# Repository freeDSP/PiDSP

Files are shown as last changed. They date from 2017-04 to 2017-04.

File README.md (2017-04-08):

# PiDSP
Home of PiDSP - a freeDSP for Raspberry Pi

PiDSP is a DSP board built around ADAU1452, with use of Raspberry Pi compatible SBC in mind.
For more details please see:

[PiDSP Manual](https://docs.google.com/document/d/19vuj6VbJ9ktcaG_P7PJXTnH1ImkcPwiqC4xYBWqMJs8)

[Developement thread](http://www.diyaudio.com/forums/digital-line-level/268660-freedsp-v2-0-adau1452-developement-thread-20.html)

**Specifications:**

* Power supply 12V
* Logic level 3.3V  NOT 5V TOLERANT!!
* PCB:10cmx10cm 4L - nope, you can not etch it on your sink. But it fits into 10x10cm dimension limit of cheap fab houses :)
* Inputs: 1xSPDIF, 4xI2S - TDM capable
* Outputs: 1xSPDIF, 4xI2S - TDM capable
* ADAU1452 controls: 4 analog controls, 4 digital controls
* Other: 
  * Connector for Raspberry Pi compatible SBC connector, 
  * USBi connector
  * Power management

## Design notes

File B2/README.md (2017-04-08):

# Version B2

This version is functional with some minor modification. This is not the final version. Developement is underway to fix the bugs.
Due to BOM generation, schematics contains some parts that are not present on the pcb. Schematics and PCB are not synchronized. PCB is as it was at time of gerber generation. 

"Bugs highlight":
* DSP_Disable signal is not working - it will turn-off whole board
* Missing fixing pads for Tosling - you need to glue it
* jumper wire needed for one timing capacitors 

[Buglist](https://docs.google.com/spreadsheets/d/1_dzgIj09PDWNxM0hXiN3Wn4PsSBpoaOSRhSJXX5WdX8/edit#gid=567249624)

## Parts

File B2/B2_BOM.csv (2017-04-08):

Designator | Quantity | Comment | Description | Supplier 1 | Supplier 2 | Supplier Part Number 1 | Supplier Part Number 2 | Footprint
CK1, CK3, CK4, CK5, CK6, CK7, CK8, CK10, CK11, CK12, CK14, CK15, CK16, CK17, CK18, CK19, CK20, CK21, CK22, CK23, CK34, CK35, CK36, CK37, CK38, CK39, CK42, CK43, CK48, CK51, CK52, CK53, CK54, CK65, CK68, CK70, CK71, CK72, CK73, CK74, CK75, CK76, CK77, CK78, CK79, CK80, CK83 | 47 | 100n | MLCC | Mouser |  | 81-GRM39X104K50D |  | CAPC1608X09N(SMC0603)
CK46, CK63, CK64, CK91, CK92, CK93, CK98, CK99, CK100, CK101, CK102, CK103, CK104, CK105, CK106, CK107, CK123, CK124, CK125 | 19 | 10n | MLCC | Mouser |  | 81-GRM39X103K50D |  | CAPC1608X09N(SMC0603)
CK2, CK25, CK26, CK27, CK28, CK29, CK30, CK41, CK44, CK45, CK47, CK56, CK59, CK61, CK62, CK81, CK82, CK88 | 18 | 10u | MLCC | Mouser |  | 81-GRM31CR61H106MA2L |  | CAPC3216X12N(SMC1206)
R1, R2, R3, R6, R8, R16, R18, R19, R26, R27, R28, R29, R30, R31, R40, R61, R65 | 17 | 22R | Chip Resistor | Mouser |  | 603-RC0603FR-0722RL |  | RESC1608X06N(SMR0603)
R5, R9, R11, R12, R14, R22, R23, R24, R25, R35, R63, R67 | 12 | 4k3 | Chip Resistor | Mouser |  | 603-RC0603FR-074K3L |  | RESC1608X06N(SMR0603)
R10, R21, R42, R43, R66, R76, R81, R88 | 8 | 10k | Chip Resistor | Mouser |  | 603-RC0603FR-0710KL |  | RESC1608X06N(SMR0603)
R44, R45, R46, R47, R48, R49, R50, R51 | 8 | 100R | Chip Resistor | Mouser |  | 603-RC0603FR-07100RL |  | RESC1608X06N(SMR0603)
R17, R20, R57, R71, R83, R90 | 6 | 220k | Chip Resistor | Mouser |  | 603-RC0603FR-07220KL |  | RESC1608X06N(SMR0603)
CE1, CE7, CE14 | 3 | 330u | Polymer Aluminium Solid Capacitor 330uF, 6.3V | Mouser |  | 710-875105144010 |  | CAPAE6.8X6.8(D_SIZE)
CK31, CK32, CK66 | 3 | 22p | MLCC | Mouser |  | 81-GCM1885C1H220J16D |  | CAPC1608X09N(SMC0603)
DIO 0, DIO 1, DIO 2 | 3 | EJ-MLW16G | IDC Male Header for PCB 2x8 Pin, Straight | Mouser |  | 710-61201621621 |  | MLW16G
L5, L8, L9 | 3 | 1500R/100MHz | Multilayer SMD Ferrite 1500R/100MHz | Mouser |  | 810-MMZ2012Y152B |  | INDC2012X08N(SML0805)
R38, R68, R84 | 3 | 2k7 | Chip Resistor | Mouser |  | 603-RC0603FR-072K7L |  | RESC1608X06N(SMR0603)
T2, T3, T4 | 3 | BSS138 | N-MOSFET, Logic Level, 50V/0,22A/3.5Ohm | Mouser |  | 512-BSS138 |  | SOT95P230X110-3N(SOT23)
CE2, CE6 | 2 | 100u | Polymer Aluminium Solid Capacitor 100uF, 16V | Mouser |  | 710-875105344010 |  | CAPAE6.8X6.8(D_SIZE)
J7, J9 | 2 | UFL | Subminiature connector | Mouser |  | 571-1909763-1 |  | U.FL-R-SMT
L1, L2 | 2 | 6.8u/1.5A | Low Profile, High Current Inductor | Mouser |  | 70-IFSC1515AHER6R8M0 |  | INDM_3.8x3.8x1.8
X1, X2 | 2 | NZ2520SD | Low Phase Noise Oscillator |  |  |  |  | 2.5x2mm osclillator
CK13 | 1 | 150p | MLCC | Mouser |  |  |  | CAPC1608X09N(SMC0603)
CK9 | 1 | 5.6n | MLCC | Mouser |  |  |  | CAPC1608X09N(SMC0603)
DL3 | 1 | GREEN | Green LED, 0603 | Mouser |  | 710-150060GS75000 |  | 0603diode
DS1 | 1 | 5A/40V | High Current Density SMT Schottky Rectifier, 5A/40V, SMC | Mouser |  | 625-SSC54-E3 |  | DIOM6959X26M(SMC)
DS2 | 1 | B340A | High Current Density SMT Schottky Rectifier, 3A/40V, SMA | Mouser |  | 621-B340-F |  | DIOM5127X23N(SMA)
DZ1 | 1 | SMAJ24CA | Surface Mount TVS, Bidirectional, 12V DC Standoff, 1.5kW, SMC | Mouser |  | 652-SMAJ16CA |  | DIOM5127X23N(SMA)
J1 | 1 | NEB 21R | Power Jack Socket 1.95/6mm | Mouser | Farnell | 490-PJ-050AH | 1217037 | NEB 21 R
J11 | 1 | 2x5 | IDC Male Header for PCB 2x5 Pin, Straight | Mouser |  | 710-61201021621 |  | MLW10G_BK
J6 | 1 | MLW 2x10 | MLW 2x10 | Mouser |  | 710-61202021621 |  | MLW20G_BG
L3 | 1 | 3.3uH/6.5A | SRP6540 Series - Shielded Power Inductors | Mouser |  | 652-SRP6540-3R3M |  | INDM_7.2x6.5
L6 | 1 | 500Ohm/100MHz | CHOKE, COMMON, 4A, 500OHM, 100MHZ | Mouser |  | 81-DLW5BTM501SQ2L |  | DLW5BT
R33 | 1 | 0R1 | Chip Resistor | Farnell |  | 8867364 |  | RESC1608X06N(SMR0603)
R36 | 1 | 820R | Chip Resistor | Mouser |  | 603-RC0603FR-07820RL |  | RESC1608X06N(SMR0603)
R39 | 1 | 150k | Chip Resistor | Mouser |  | 603-RC0603FR-07150KL |  | RESC1608X06N(SMR0603)
R72 | 1 | 47k | Chip Resistor | Mouser |  | 603-RC0603FR-0747KL |  | RESC1608X06N(SMR0603)
R86 | 1 | 56k | Chip Resistor | Mouser |  | 603-RC0603FR-0756KL |  | RESC1608X06N(SMR0603)
T1 | 1 | FDC658AP | 30V P - Channel PowerTrench MOSFET | Mouser |  | 512-FDC658AP |  | TSOP95P280X110-6N(SuperSOT6)
U1 | 1 | ADAU1452 | ADAU1452 | Mouser |  | 584-ADAU1452WBCPZ |  | CP_72_6-handsoldering
U10 | 1 | LP5907 3.3V | Ultra Low-Noise, 250-mA Linear Regulator | Mouser | Digi-Key | 595-LP5907MFX-3.3NPB | 296-38557-1-ND | SOT95P280X90-5N(SOT23-5)
U11 | 1 | TPS54292 | 1.5-A/2.5-A Dual, Fully-Synchronous Buck Converter | Mouser |  | 595-TPS54292PWPR |  | TSOP65P640X120_HS-17M(TSSOP16-TP)
U14 | 1 | CAT24C512 | 512 Kb I2C CMOS Serial EEPROM | Mouser |  | 863-CAT24C512WI-GT3 |  | SOIC127P600X175-8N(SOIC_8)
U15 | 1 | SP4065 | 3.3V 20A Diode ESD Array | Mouser |  | 576-SP4065-08ATG |  | TSSOP50P490X110-10N(MSOP10)
U2 | 1 | Si53360 | 1:8 LOW JITTER CMOS CLOCK BUFFER WITH 2:1 INPUT MUX | Mouser |  | 634-SI53360-B-GT |  | TSOP65P640X120-16N (TSSOP16-4.4MM)
U4 | 1 | RPi B+/2/3 | Rapsberry Pi Header | Mouser |  | 517-929975-01-20 |  | RPi B+
U6 | 1 | OTJ-8 | Toslink Transmitter | TME |  | FC684208T |  | OTJ/ORJ 8
U7 | 1 | ORJ-8 | Toslink Reciever | TME |  | FC684208R |  | OTJ/ORJ 8
U8 | 1 | LTC2950-1 | Pushbutton On/Off Controller | Farnell |  | 2115908 |  | LT-TS8-8-TSOT-23_V
U9 | 1 | TPS54360 | 3.5 A, Step Down DC-DC Converter | Mouser |  | 595-TPS54360DDAR |  | SOIC127P600X175-8N(SOIC_8)-POWERPAD

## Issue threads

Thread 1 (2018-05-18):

Where to order PCB?

mbt28, 2018-05-18:
Hi,

How is the development status of beta revision? Can you please tell me low-cost pcb ordering place for the piDSP?

Thanks

Pitrsek, 2018-05-22:
Hi,
last time I've ordered from elecrow, but there are many possibilities. If you don't mind B2 version, i can put one or two into an envelope and send it your way :). B2 is missing possibility to turn of freedsp expansion boards(and some minor fixable bugs).I can add two milled boards that will add the turn off capability and fix startup timing.
About next version - i've finished incorporating all the changes and checked the design, I need to upload it for a review and order boards. My guess is that I'll have it tested by mid summer.

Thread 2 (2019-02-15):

Pinout of Toslink wrong?

DanieGieb, 2019-02-15:
Hello,

I am currently designing a board and use your implementation as a good  inspiration ;-)
Did you already tested the Toslink part?

In the Schematic the receiver U7 (ORJ-8) and the transmitter U6 (OTJ-8) have different pining as specified by the datasheet.

Datasheets:
Receiver: [http://www.cliffuk.co.uk/products/optical/FCR684208R.pdf](url)
Transmitter: [http://www.cliffuk.co.uk/products/optical/FCR684208T.pdf](url)

Maybe you have different footprint numbering and therefore it is correct?
Or is the part wrong?
By the way: Do you suggest to use this part? Availability?

Kind Regards
Daniel

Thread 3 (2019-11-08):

B3 still work in progress?

unre4l, 2019-11-08:
Great project so far! I am wondering if there is any active development going on?

Pitrsek, 2019-12-30:
Hello Jonathan, not really. I have a few boards that are up and running, I have made some final modifications, but I did nod had energy to push them and finish it up. ie. built the final design for verification. Life happened - I changed job and country, this Xmass we have moved again. I have some spare boards left, if you dont mind adding a few wires here and there.

Cheers,
Jan

myreauks, 2023-04-02:
Hi!

I am digging up this thread from a long time ago. I would be interested in carrying on this project. I have designed my own ADAU1701 board to be used with raspi but would like to transfer my design to use ADAU1452 to have easy support for S/PDIF. Do you have any documentation on the changes you were about to make for the B3 version of the board? Or on the off chance you would still have some B2 board lying around, would you be willing to sell one for testing purposes?

Best regards,
Miro

Pitrsek, 2023-04-04:
Hi,
if I remember correctly there was some minor bug wrt soft start. I can take a look at the board I've been using ever since, take a picture and write few notes about what and why was modified. I do still have some boards. How many you'd need? I'll be happy to send them your way.

Cheers,
Jan

myreauks, 2023-04-05:
Nice, that would be awesome! I'll contact you through your website.

Best,
Miro

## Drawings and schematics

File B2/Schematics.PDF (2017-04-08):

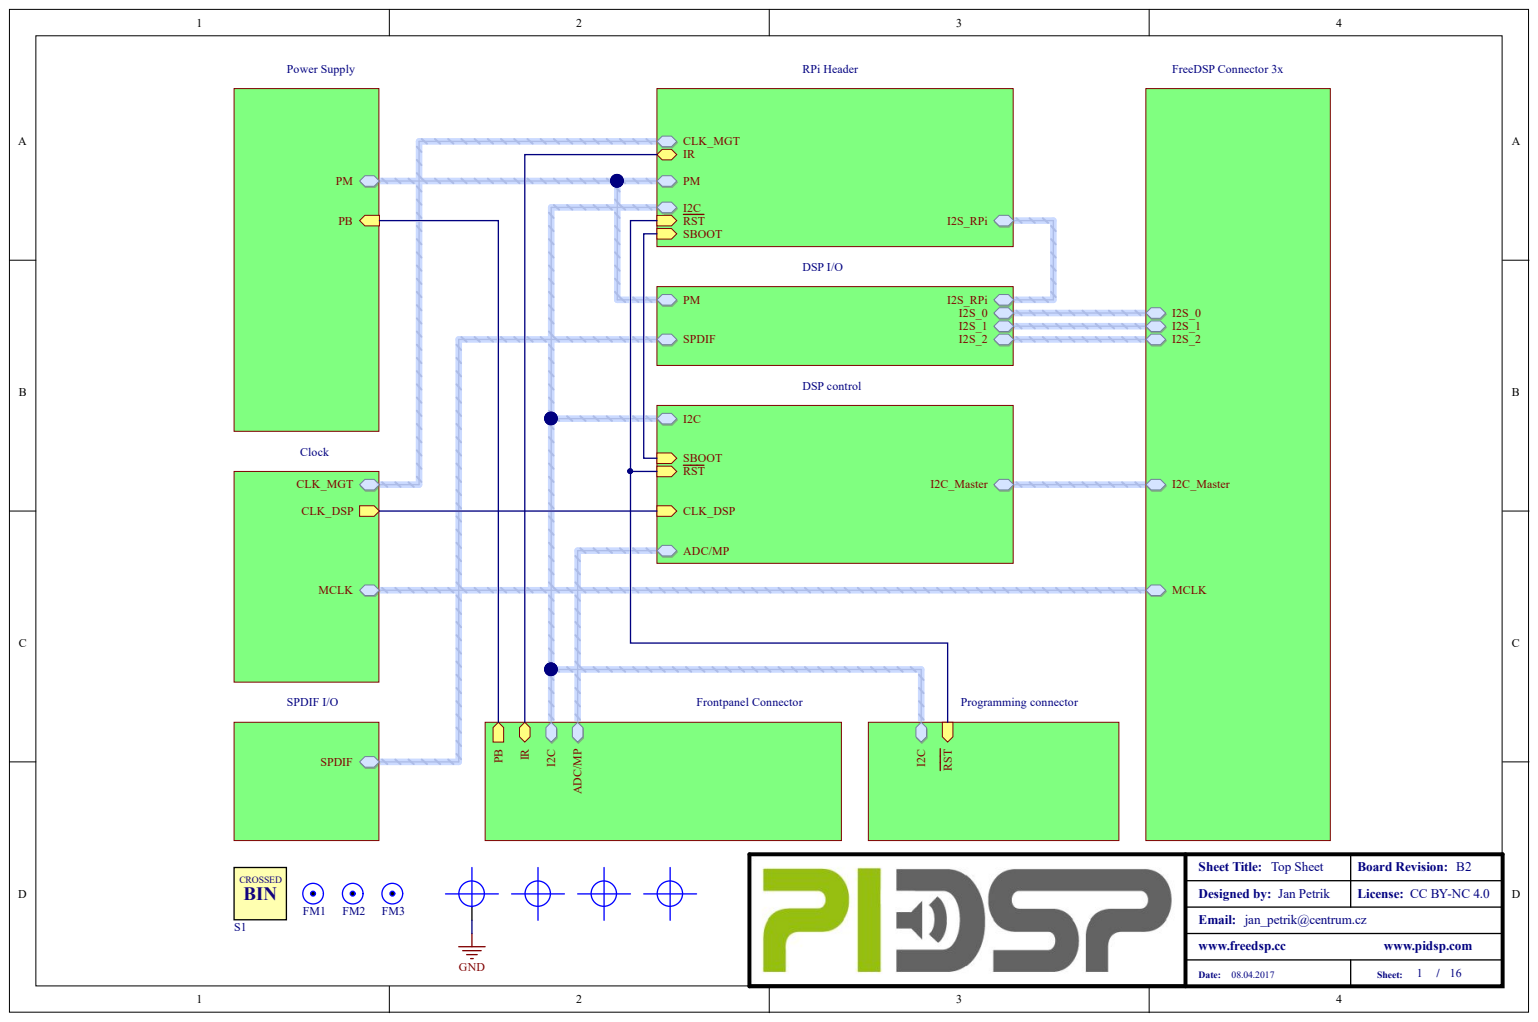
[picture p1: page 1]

Fro n t panel Co n nect o r

SPDIF

S h e et T itl e : Top She e t | Boar d R evi s ion : B2

D e s ign e d by: J an P e tri k | Li c e n s e : CC BY-NC 4. 0

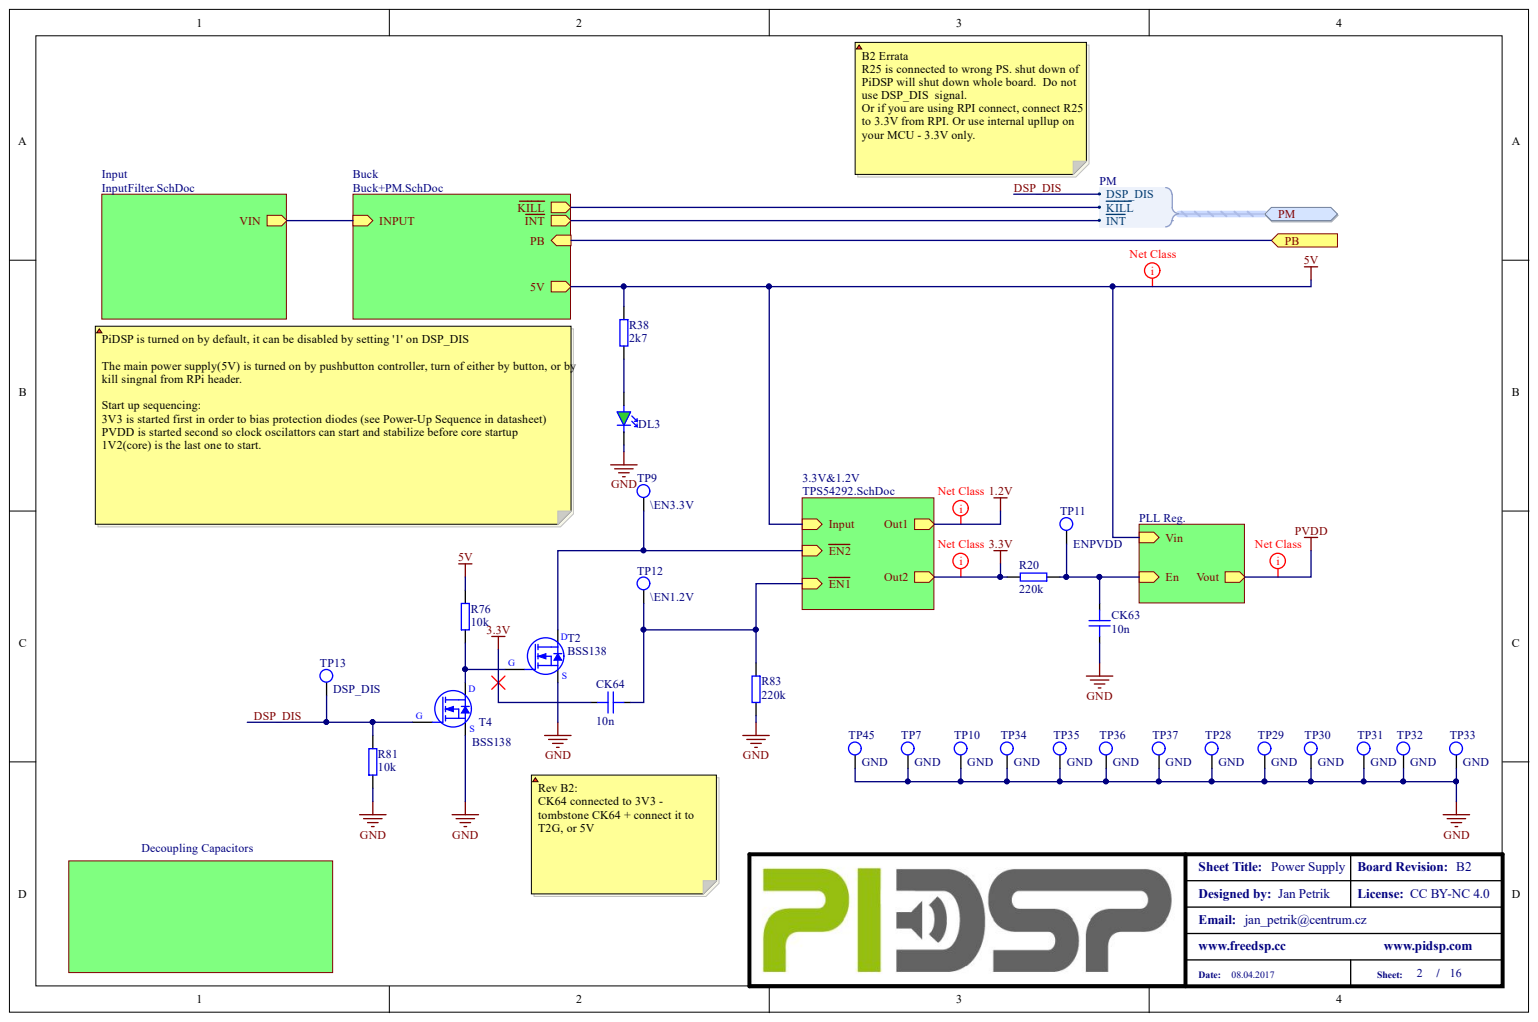
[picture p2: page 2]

B2 Errata
R25 is connected to wrong PS. shut down of
PiDSP will shut down whole board. Do not
use DSP_DIS signal.
Or if you are using RPI connect, connect R25
to 3.3V from RPI. Or use internal upllup on
your MCU - 3.3V only.

PiDSP is turned on by default, it can be disabled by setting '1' on DSP_DIS

The main power supply(5V) is turned on by pushbutton controller, turn of either by button, or by
kill singnal from RPi header.

Start up sequencing:
3V3 is started first in order to bias protection diodes (see Power-Up Sequence in datasheet)
PVDD is started second so clock oscilattors can start and stabilize before core startup
1V2(core) is the last one to start.

Rev B2:
CK64 connected to 3V3 -
tombstone CK64 + connect it to

Sheet Title: Power Supply | Board Revision: B2

Designed by: Jan Petrik | License: CC BY-NC 4.0

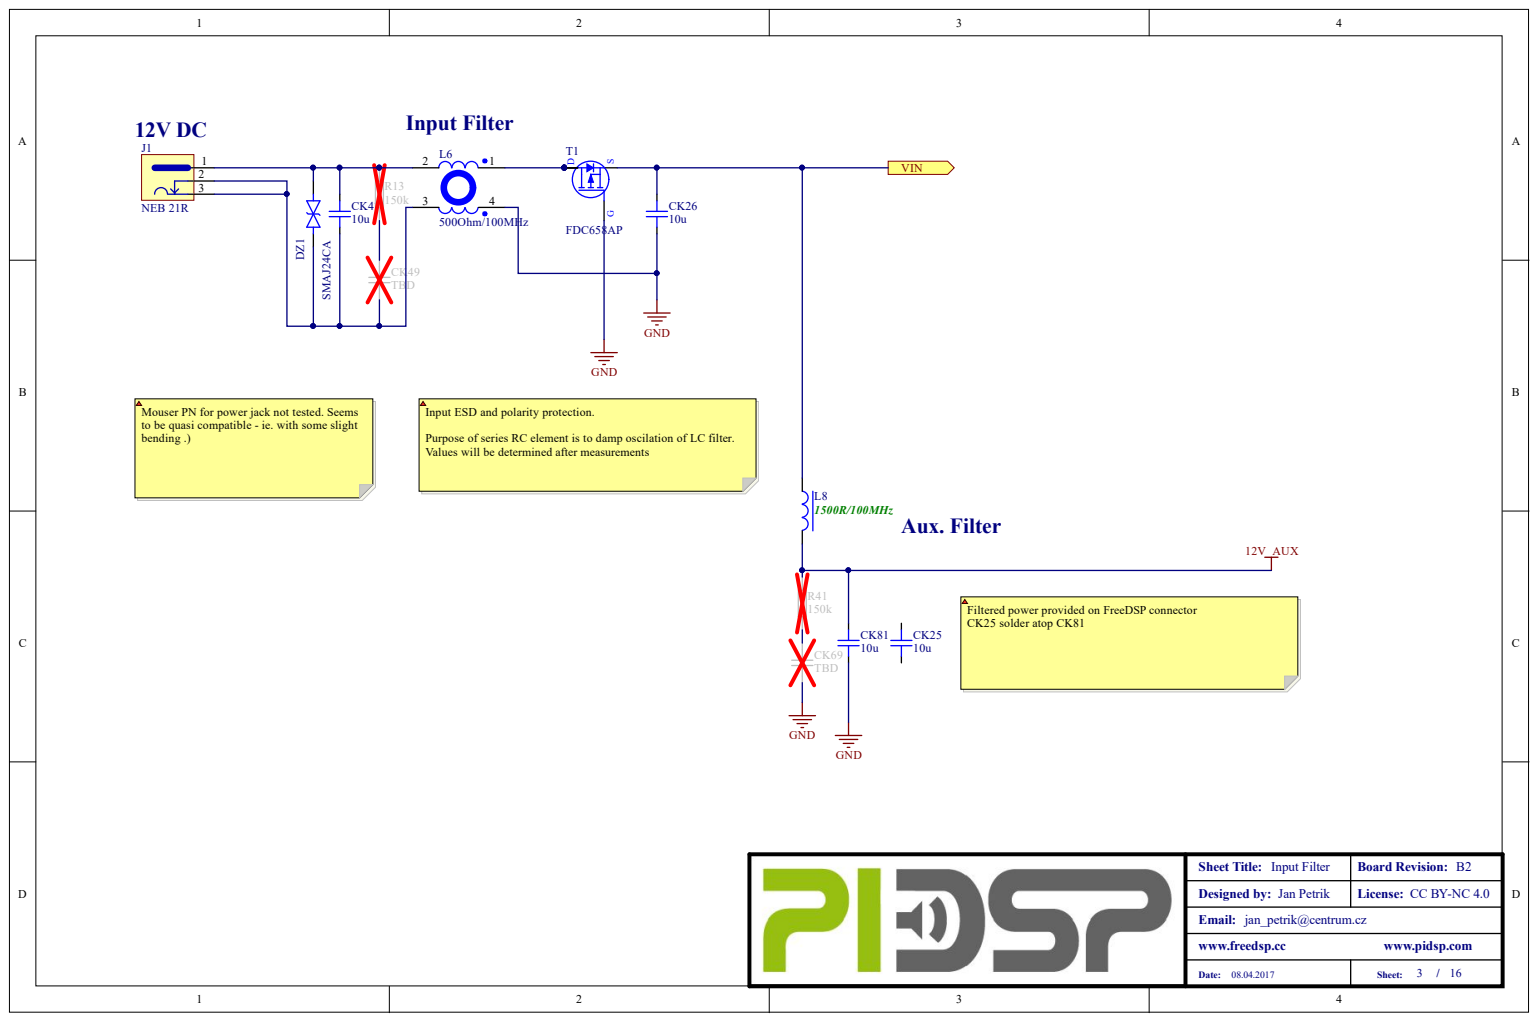
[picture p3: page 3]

Mouser PN for power jack not tested. Seems
to be quasi compatible - ie. with some slight
bending .)

Input ESD and polarity protection.

Purpose of series RC element is to damp oscilation of LC filter.
Values will be determined after measurements

Filtered power provided on FreeDSP connector
CK25 solder atop CK81

Sheet Title: Input Filter | Board Revision: B2

Designed by: Jan Petrik | License: CC BY-NC 4.0

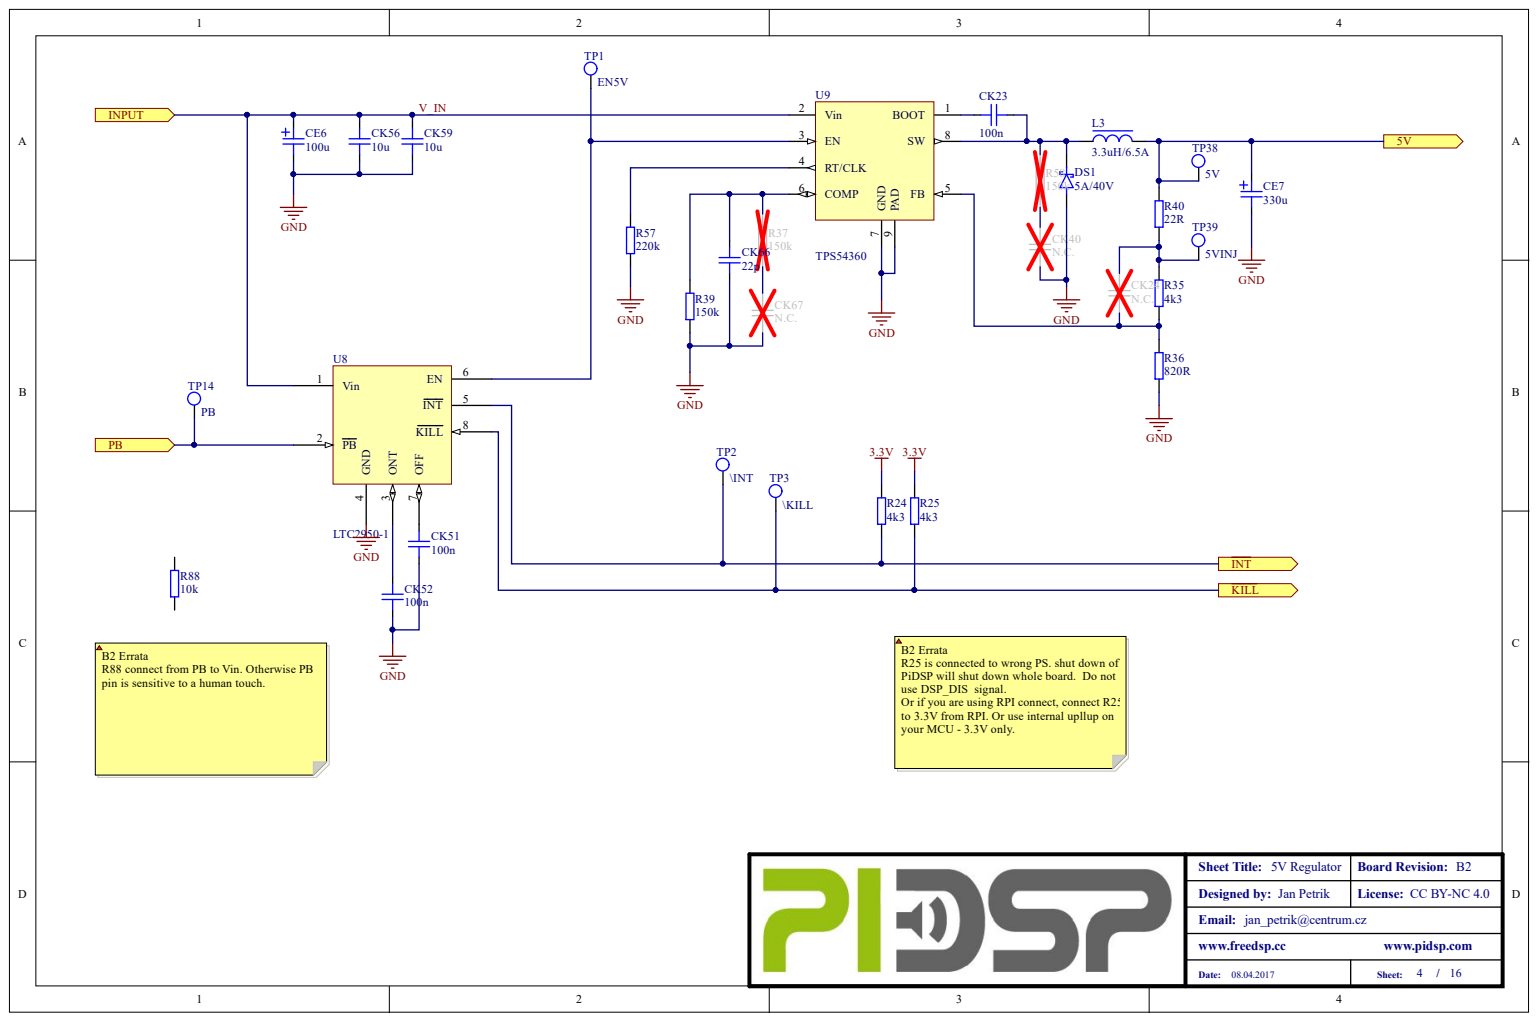
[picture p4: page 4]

S h e et T itl e : 5V Regul a tor | Boar d R evi s ion : B2

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

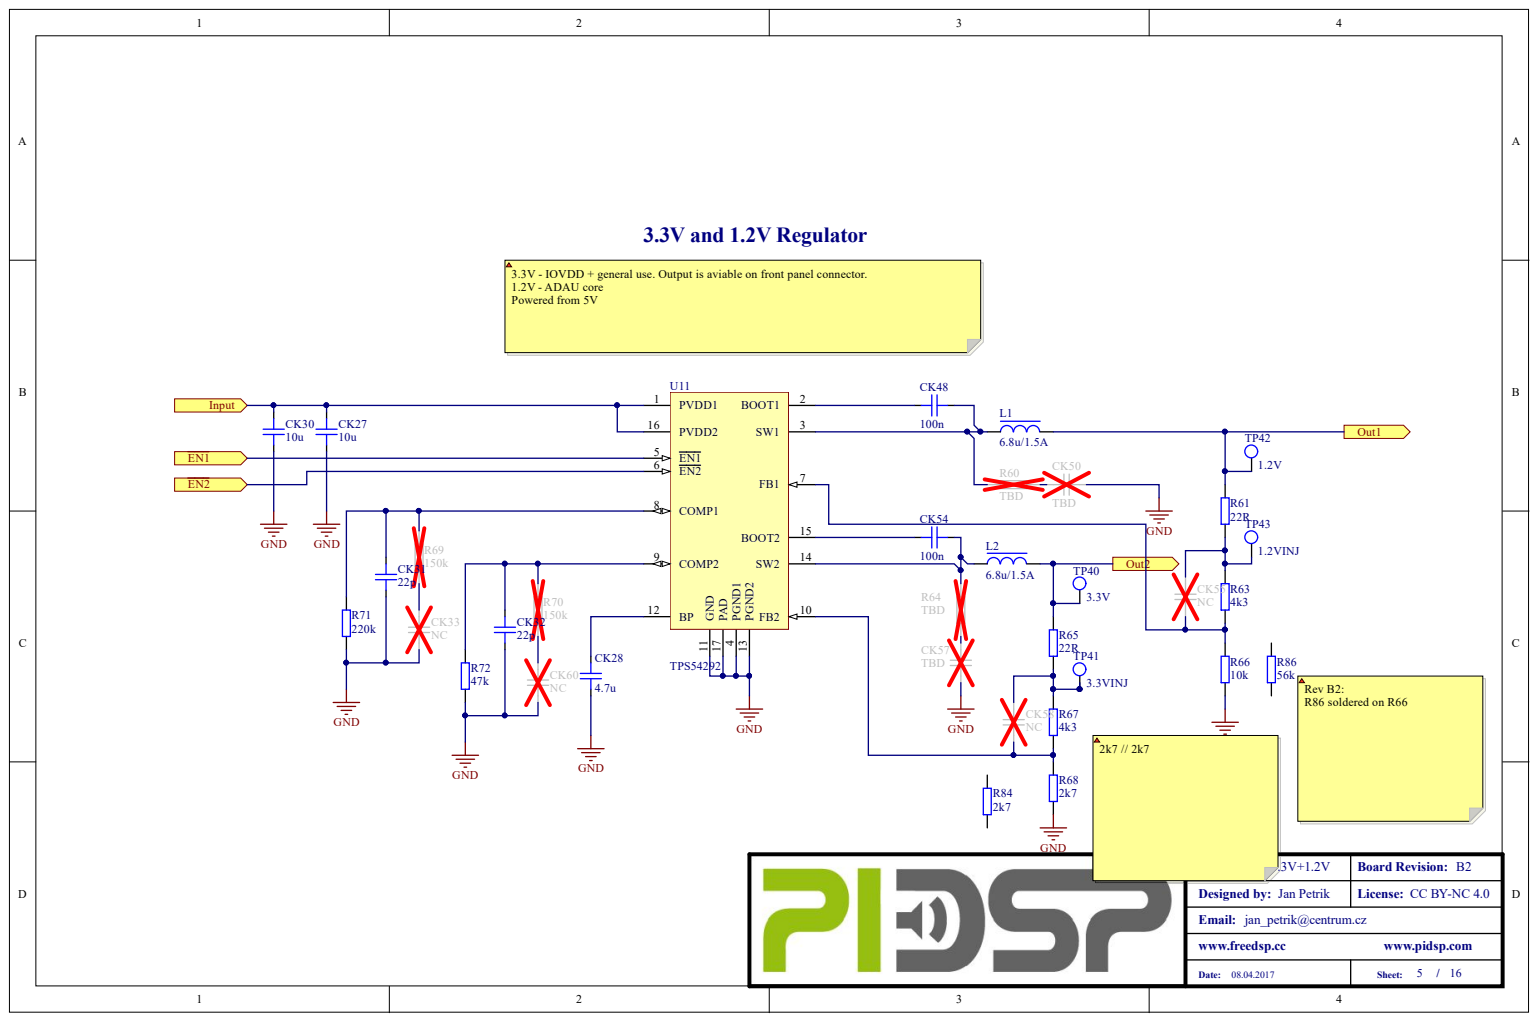
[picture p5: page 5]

S h e et T itl e : 3.3V+1.2V | Boar d R evi s ion : B2

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

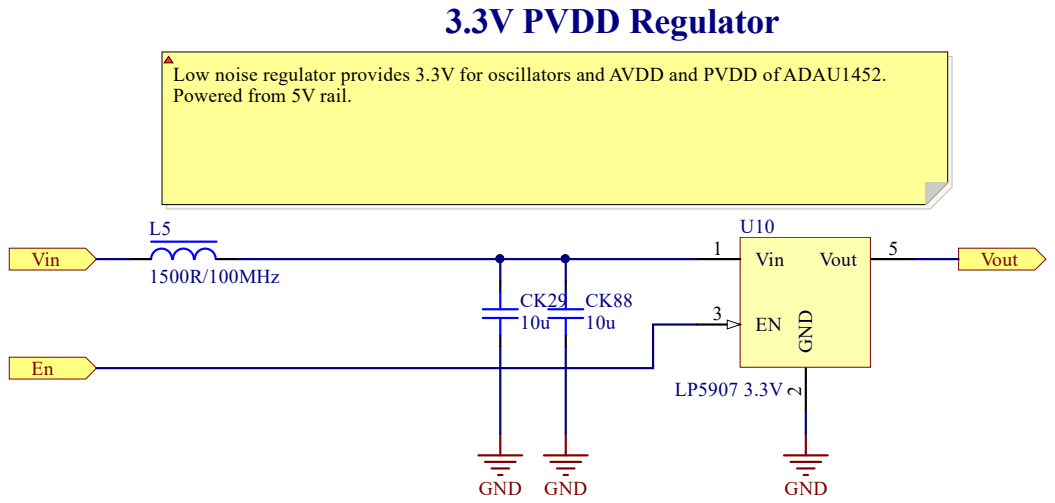
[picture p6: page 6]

S h e et T itl e : P V D D | Boar d R evi s ion : B2

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

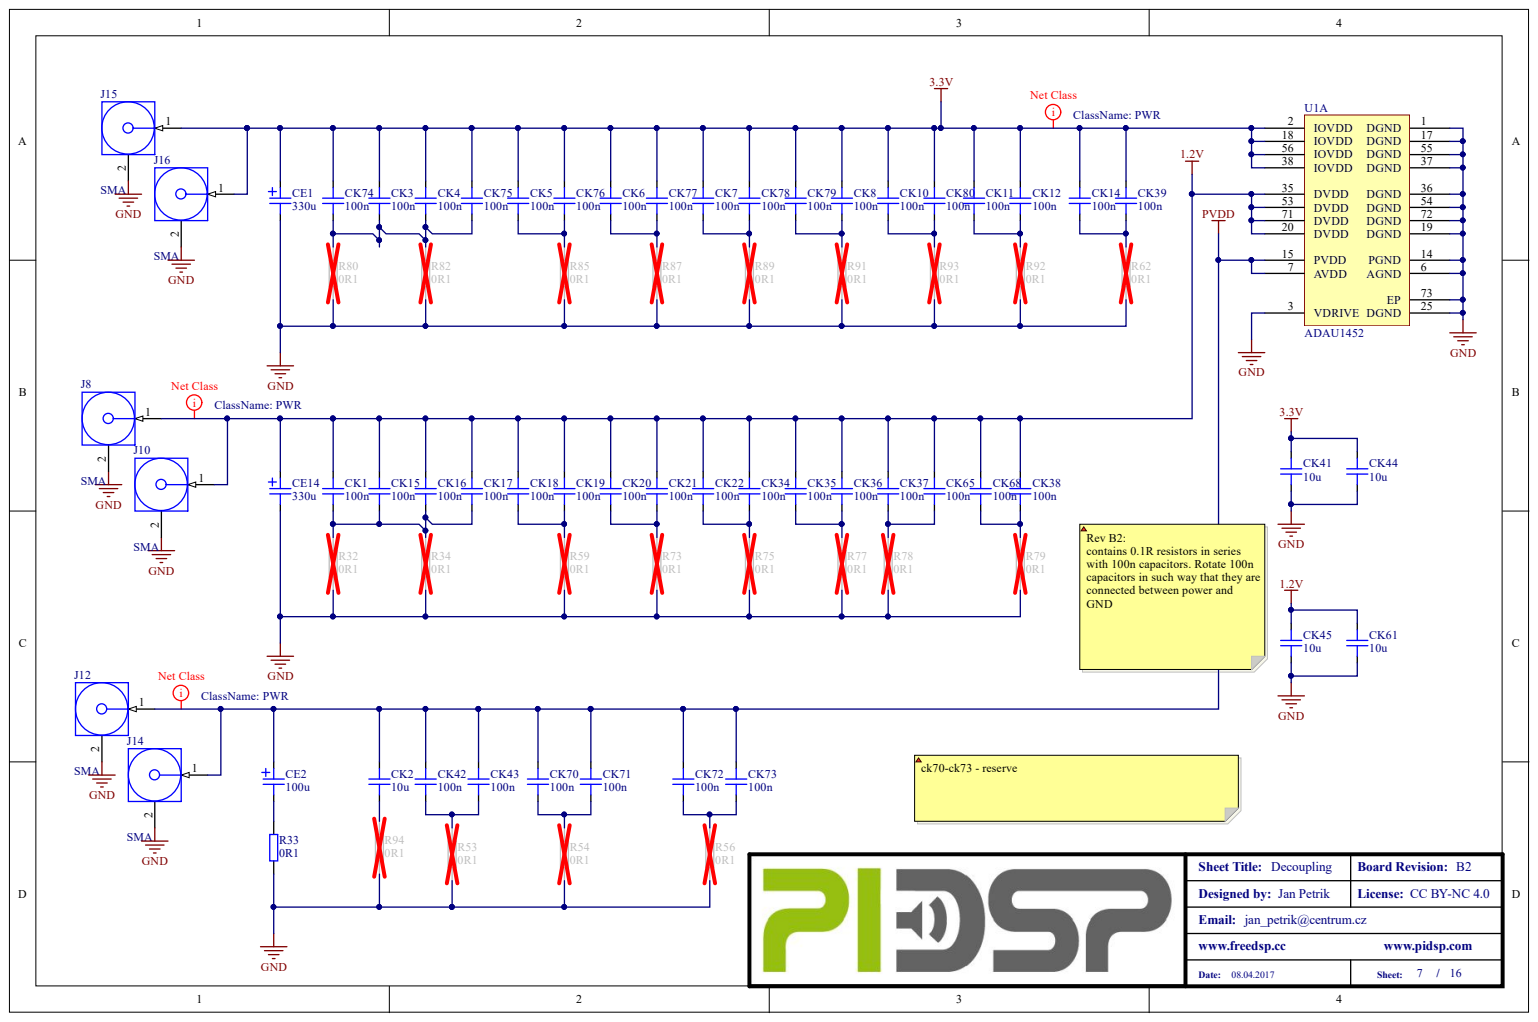
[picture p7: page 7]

Rev B2:
contains 0.1R resistors in series
with 100n capacitors. Rotate 100n
capacitors in such way that they are
connected between power and
GND

Sheet Title: Decoupling | Board Revision: B2

Designed by: Jan Petrik | License: CC BY-NC 4.0

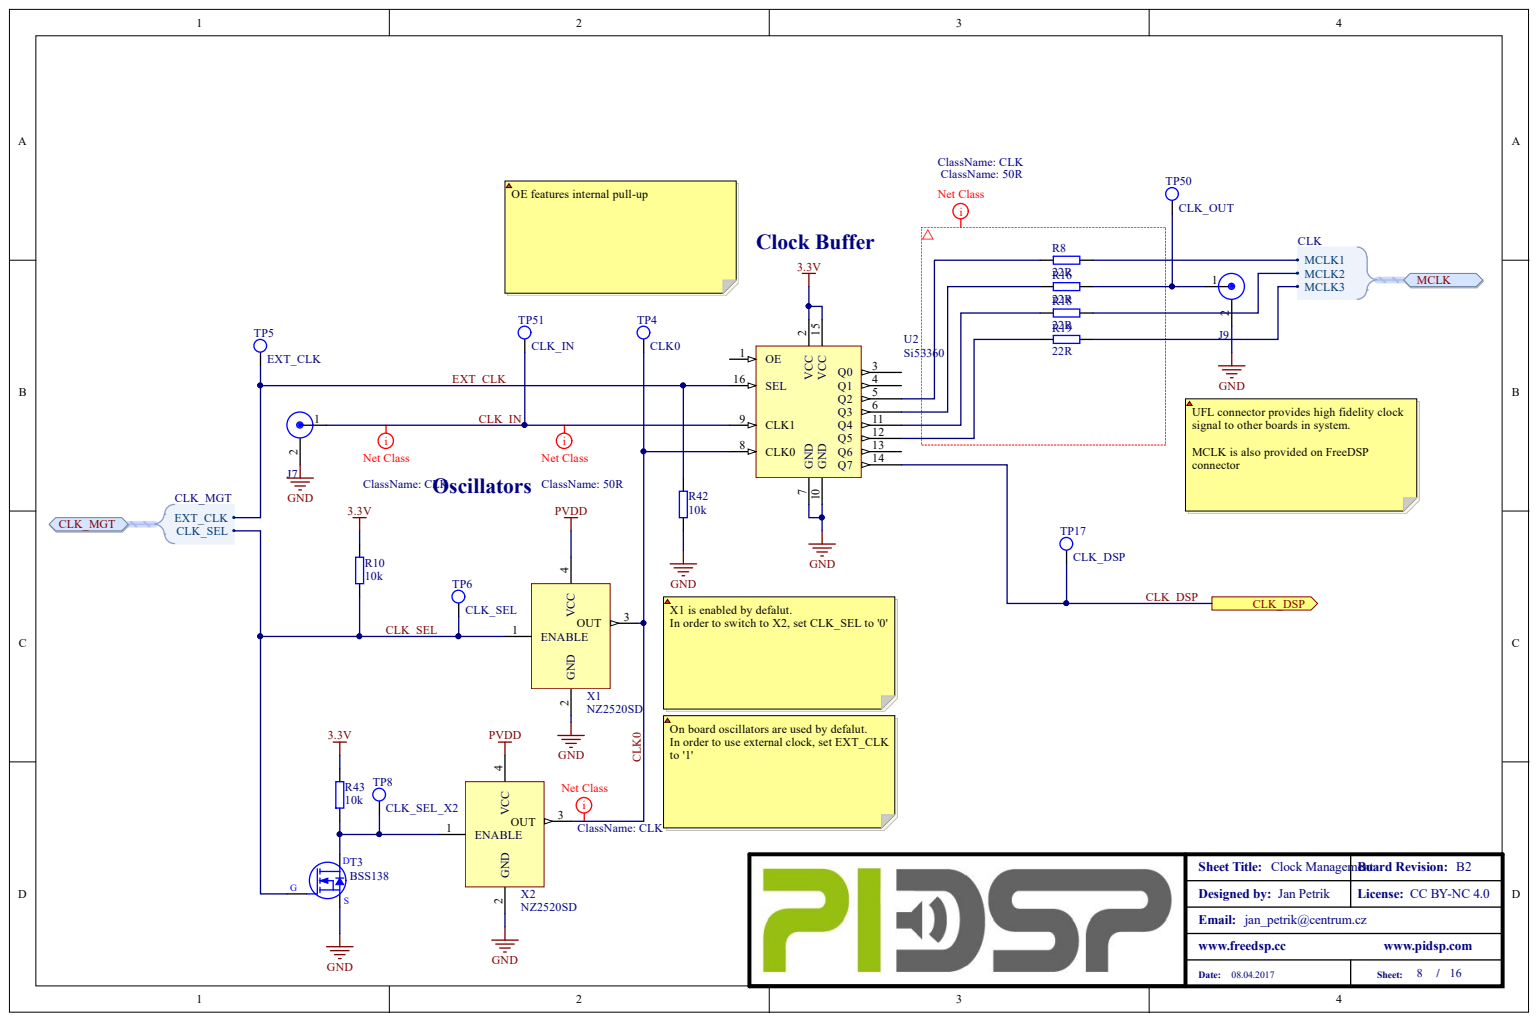
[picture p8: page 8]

1 1

S h e et T itl e : Clock M anage m | Boar ent d R evi s ion : B2

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

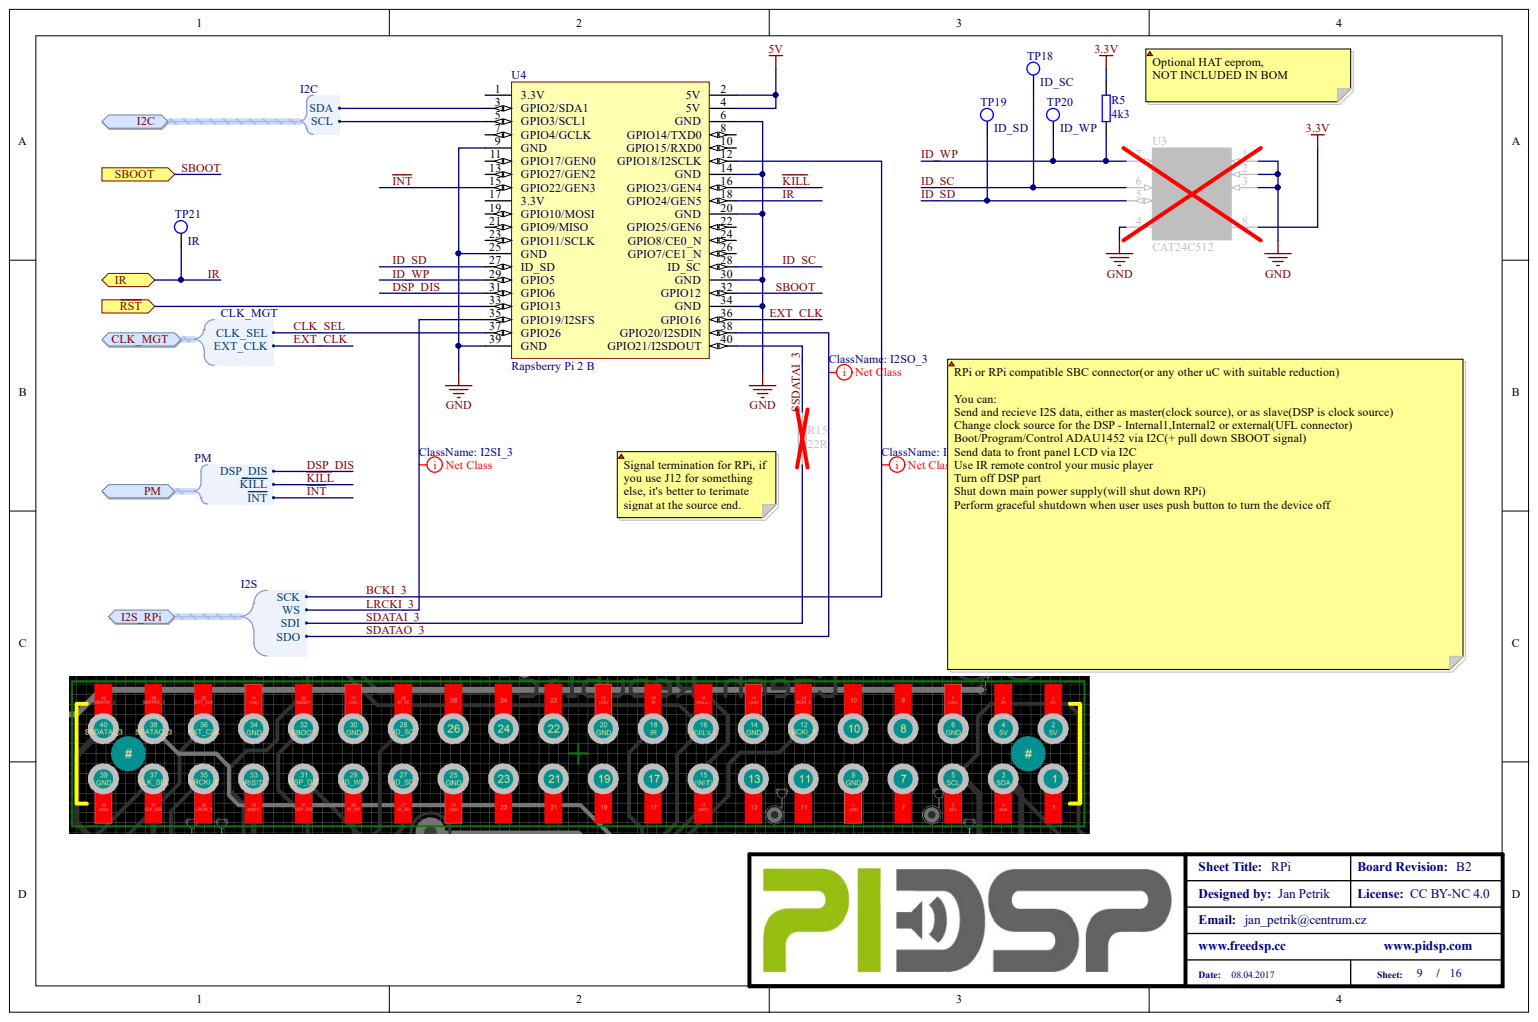
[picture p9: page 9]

2 1 | 2 2
2 3 | 2 4
2 5 | 2 6

RPi or RPi compat

KIL L IN T BCKI_ 3 | y o u u se J 1 2 for s omet h i n g el se, i t's bet ter t o terimate s i g nat at t he s o urce en d .

LRCKI_ 3

S h e et T itl e : RP i | Boar d R evi s ion : B2

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

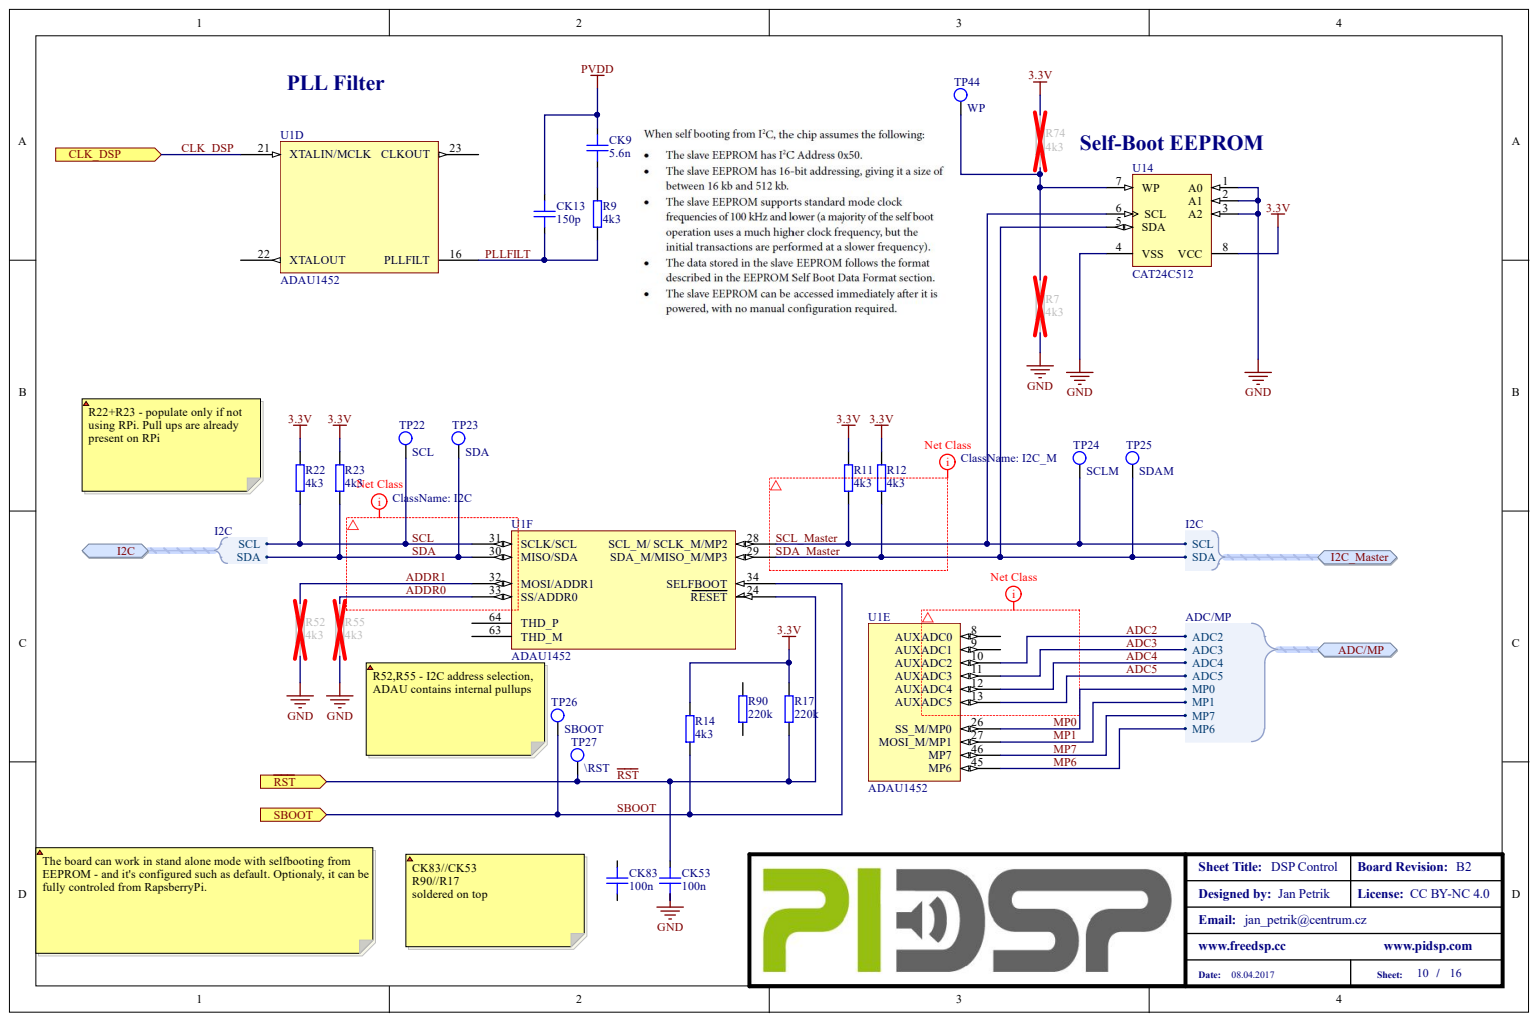
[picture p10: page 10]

R22+R23 - populate only if not
using RPi. Pull ups are already
present on RPi

ADDR0

R52,R55 - I2C address selection,
ADAU contains internal pullups

The board can work in stand alone mode with selfbooting from
EEPROM - and it's configured such as default. Optionaly, it can be
fully controled from RapsberryPi.

Sheet Title: DSP Control | Board Revision: B2

Designed by: Jan Petrik | License: CC BY-NC 4.0

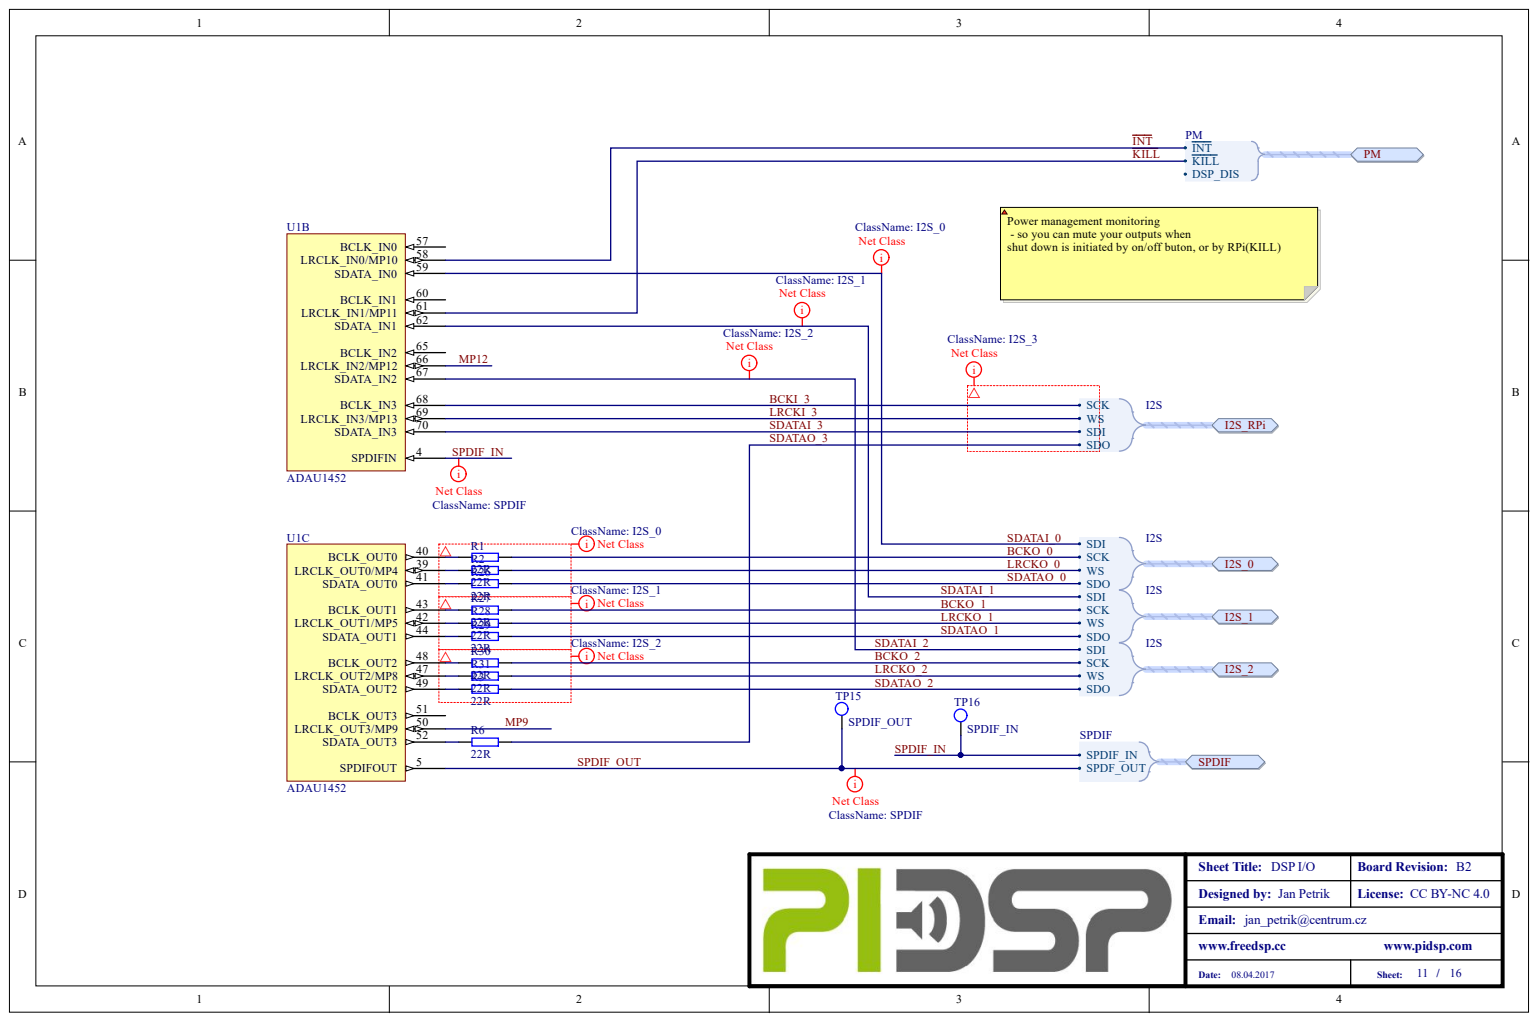
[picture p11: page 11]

Power management monitoring
- so you can mute your outputs when
shut down is initiated by on/off buton, or by RPi(KILL)

22R R3 | SDATAO_2

Sheet Title: DSP I/O | Board Revision: B2

Designed by: Jan Petrik | License: CC BY-NC 4.0

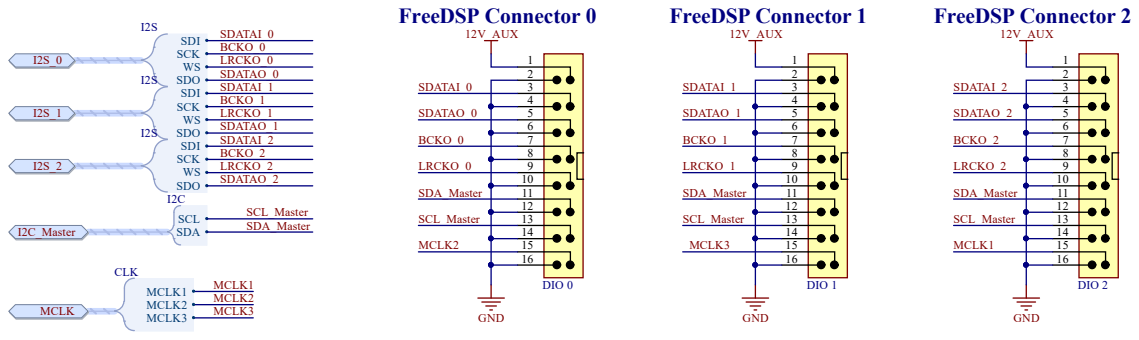
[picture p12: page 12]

S h e et T itl e : I/ O Conne c tors | Boar d R evi s ion : B2

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


S h e et T itl e : T i t l e | Boar d R evi s ion : B2

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


Programing connector for USBi

Use it to program your DSP. PiDSP can be powered from USBi.
Power is NOT provided to other modules connected via FreeDSP connector

Sheet Title: Title | Board Revision: B2

Designed by: Jan Petrik | License: CC BY-NC 4.0


MMP7 | 123456789
3.3 v _FP
MMP6

MMP1

SCL SD A IR PB A A DC5

1 9
2 0

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


GPIO/ADC ESD Protection

Sheet Title: ESD Protection | Board Revision: B2

Designed by: Jan Petrik | License: CC BY-NC 4.0

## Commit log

2017-04-08 Schematic amd readme comit for version B2
2017-04-08 Update README.md
    added remark about pcb and sch sync
2017-04-08 B2 Source file commit
    [B2_BOM.csv]
2017-04-08 Initial Commit for development branch
    [Buck+PM.SchDoc, DSP.SchDoc, DSPPower.SchDoc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]
2017-04-08 First batch of bugfixes implemented
    [Buck+PM.SchDoc, DSPPower.SchDoc, DSP_DIO.SchDoc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]
2017-04-09 more bug fixes
    [InputFilter.SchDoc, PowerSupply.SchDoc]
2017-04-09 implemented 12Dis, started to add silk to connectors, some layout work
    [DSP_DIO.SchDoc, FrontPanelConnector.SchDoc, InputFilter.SchDoc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]
2017-04-10 curent consumption test-points
    [LP5907MFX-3.3NPB.SchDoc, PiDSP.PrjPcb]
2017-04-12 more bug fixes. some layout done.
    [Buck+PM.SchDoc, DSP.SchDoc, DSPPower.SchDoc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]
2017-04-14 Buck+pm layout cleanup, improved thermal performance
    [Buck+PM.SchDoc, DSPcontrol.SchDoc, InputFilter.SchDoc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]
2017-04-15 improved layout around ESD protection
    [ESD.SchDoc, FrontPanelConnector.SchDoc]
2017-04-15 layout. silk screen clean up, and more layout. I've also removed pull up resistor at S/DPIF input.
    [SPDIF.SchDoc]
2017-04-17 more layout, testpoint and silkscreen cleanup
    [InputFilter.SchDoc, TPS54292.SchDoc]
2017-05-14 routing and DRC
    [FrontPanelConnector.SchDoc, PiDSP.PrjPcb]
2018-02-19 general celanup
    [Buck+PM.SchDoc, DSP.SchDoc, DSPPower.SchDoc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]
